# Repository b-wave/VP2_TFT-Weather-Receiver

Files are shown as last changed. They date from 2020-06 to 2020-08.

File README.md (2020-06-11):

# VP3-Weather-Receiver
*Davis Vantage Pro Weather Station Reciever using a Moteieino board with RFM69 and Color TFT Display.(1)*

This project is mainly a demo of the dekay/DavisRFM69 library (et.al.) @dekay using a TFT LCD screen 
it was intended to be a low-cost replacement for a broken Davis Vu Weather station that the ISS still works (with a few issues) 
*...but that is another story.* Hopefully *someone* will find this useful. I had a fun time developing it and
you can still see the saga of revisions in the source code listing as it evolved over several months. 

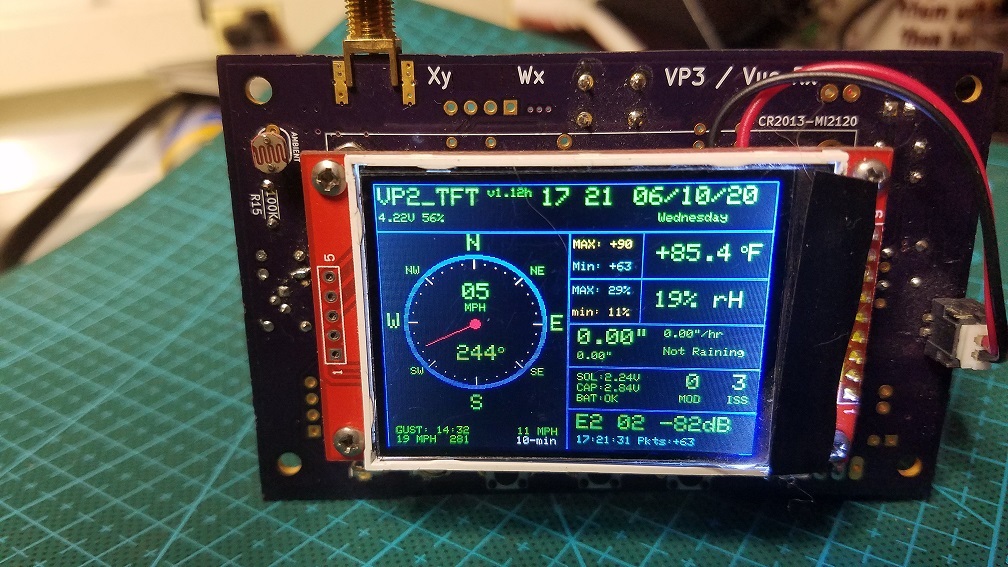
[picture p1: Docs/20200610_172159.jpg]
VP2_TFT-Weather-Receiver

Display in action - Front view

Because i used a low cost Motieno, https://lowpowerlab.com/ it ran out of memory so this version
can display mainly only the data received from the Davis Vantage Vu ISS.
With some derived info like,  max and mins, rain, and cool TFT wind compass displays. 

Curently, this project version does not  add the internal data to make a complete 
TFT console replacement for display of all weather parameters. I had to remove
indoor temp, humidity and barometric pressure to make a usable replacement. 

I designed a circuit board and added some usefull features such as push button setting
a LiPo battery backup and charger, and a real time clock.  Some features will need to move to
the: *next version that uses a Teensey 3.2 board will do all this and more!*

## CREDITS:
This is a derivitive work from several authors i give credit
to the original works in line as i use them, without their work
this would not be possible.  The original work here includes the
additions for using TFT LCD displays. But I credit to getting the 
TFT to work with the RFM69 was because of this excellent article:
 https://www.pjrc.com/better-spi-bus-design-in-3-steps/  
 Thanks Paul! @PaulStoffregen

https://github.com/kobuki/VPTools
VPTools is a Davis(TM) weather station compatible transceiver library. 
It is a work in progress. It can receive from multiple RF transmitters (ISS, ATK, etc.) 
It tries to serve as a basis for similar hobby projects. 
Example sketches provide simple, parseable and RAW packet output among others.

https://github.com/dekay/DavisRFM69  By DeKay
Licence: Creative Commons Attribribution Share-Alike License http://creativecommons.org/licenses/by-sa/3.0/
This library is a modified version of the LowPowerLab's RFM69 library that enables reception of weather data 
from a Davis Instruments Integrated Sensor Suite (ISS) weather station.

https://github.com/LowPowerLab/RFM69  By Felix Rusu, LowPowerLab.com 
RFM69 library for RFM69W, RFM69HW, RFM69CW, RFM69HCW (semtech SX1231, SX1231H) 
Licence:GPL 3.0, please see the License.txt file for details. 
Be sure to include the same license with any fork or redistribution of this library.

ADAFRUIT Libraries and awesome info:
Written by Limor Fried/Ladyada for Adafruit Industries. MIT license, 
Licence : MIT https://github.com/adafruit/RTClib/blob/master/LICENSE
https://github.com/adafruit

https://github.com/adafruit/RTClib
This is a fork of JeeLab's fantastic real time clock library for Arduino.

These libraries are for the Adafruit ILI9341 display products:  
https://github.com/adafruit/Adafruit_ILI9341
https://github.com/adafruit/Adafruit-GFX-Library

## Notes:
1. The VP3 refernce to the never produced color LCD console from Davis Instrumnents https://www.davisinstruments.com/weather-monitoring/
that all of us fans of thier products wish for.

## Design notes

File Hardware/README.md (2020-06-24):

*Davis Vantage Vu Weather Station Reciever using a Moteieino board with RFM69 and Color TFT Display*

This folder provides the hardware info for this project. The circuit board in the main page picture is an early version.  The current board will be available on OSH Park so you can just order boards if you want them as-is.  The main differences are some minor circuit fixes, a slight size adjustment (to fit in a case I have in mind for the station) and embedding the RTC and battery on the board.  The original PCB was ony intended to use plug in modules and make it a little more robust than protoboards.  From the software, which is pretty ugly, you can probabily tell I am not a software expert, but this board has a strange combo of thru-hole and SMT technologies that reflect mostly what was on hand or could get easily for this proto. is not making the hardware hall of fame either, but it works.   

# Schematic

The schematic is in KiCAD format, here it is as a .JPEG if you don't have that software. You will notice a lot of hardware features on the board are not in use in the VP3 console receiver project due to program storage space *(1)*.  If you order the boards from [OSH Park](https://oshpark.com/)  you get 3 boards so one can programmed to be a console, one can be a logger, and the third can be an APRS packet generator/controller.  ISS does not care how many receivers are listening! 

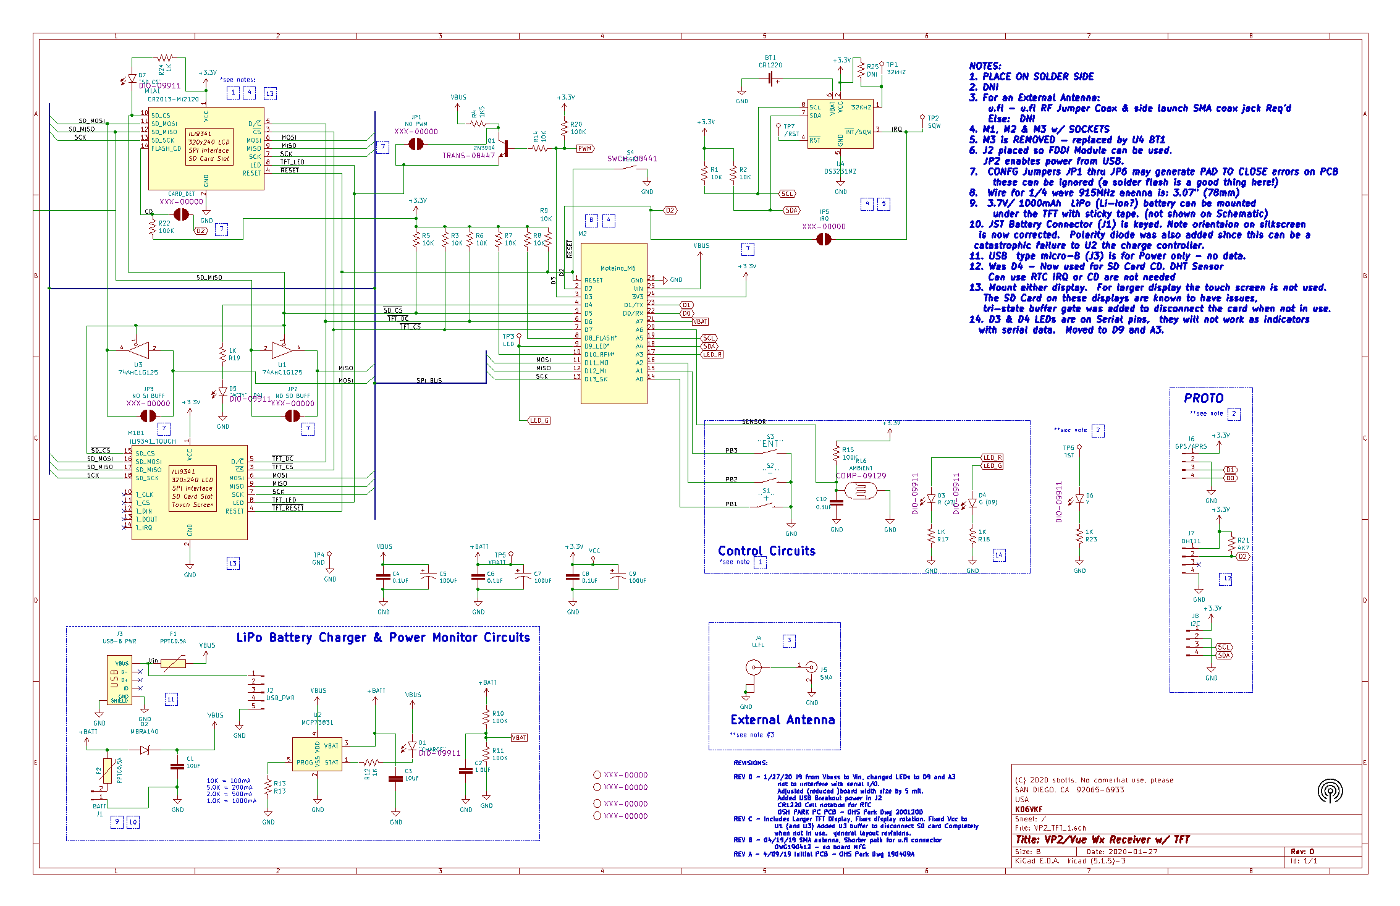
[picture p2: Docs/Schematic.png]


The circuit board is shown assembled in these 3D renderings.  The circuit board will accomodate 2 sizes of 320x240 displays. The 3D renderings also show the assembly with the smaller 2.2" display.  You can see the outline of the optional 2.8" display and that i Put the LED indicators outside its outline. The LiPo battery connector is on this side as well as it is sandwiched in between the display and main PCB.  There are 3 tactile switches:
**"+"  "-"  "GO!"**
Used to set the clock and other parameters. You may want to use the long plunger types (13mm - 15mm)  should reach thru a front or rear panel in this configuration especially if you are putting it in some sort of case. They can be mounted on either side of the board as well.  With the 2.8" display the swithes will need to be relocated as they are blocked from the front by that display. *(2)*

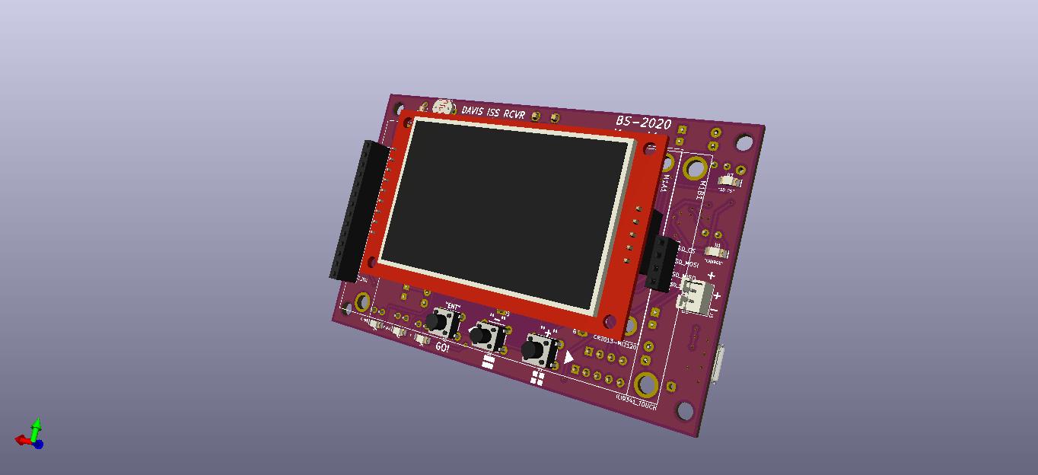
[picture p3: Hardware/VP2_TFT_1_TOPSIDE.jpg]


The back side is where the Moteino and other modules plug in. The power connectors are on the left side.  I used a mini-USB connector for just power.  The Pin out for the USB_Power_Only is setup to match the SPARKFUN Breakout board 
[BOB-09966](https://www.sparkfun.com/products/9966) enables a power plug to be moved depending on the case requirements. 

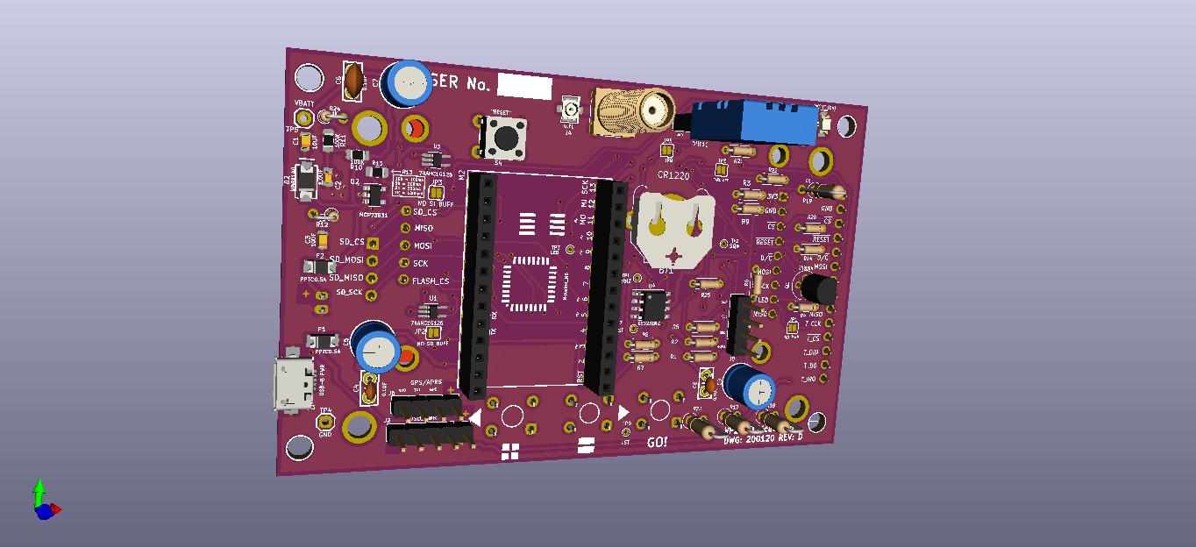
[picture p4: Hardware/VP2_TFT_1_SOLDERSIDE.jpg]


# Circuit Description

The  [Parts List](https://github.com/b-wave/VP2_TFT-Weather-Receiver/blob/master/Hardware/VP2_TFT_1.xlsx) is generated from the schematics, the format is wierd.  Not all parts are installed depending of software support and features. You may want to read through these circuit descriptions before getting parts. I also did not provide much specific supplier information yet, except for the few noted, the others are fairly common parts you can order from [Digikey](https://digikey.com) or [Mouser](https://mouser.com) or other simular suppliers. I may supply a complete parts list with suppliers used on OSH Park that are compatible with the version of board. 

* **Arduino.** The brains of this project is the **Low Power Lab** [Moteino](https://lowpowerlab.com/shop/product/99)  Remember when ordering that you must add the RFM69CW 868/916MHz RF Module option or you won't be receiving any data!  You can also get the RFM69HCW but that version has more transmit power that you really don't need for this project since we never transmit anything. Also, you can add the headers and possibly the memory chip but can use the on-chip non-volitile memory in the software. It come with a simple wire antenna that actully works OK. There is also a small $2.00 [915 MHz Helical Antenna](https://lowpowerlab.com/shop/product/160?search=antenna) you may consider ordering as well. Speaking of antennas, I went full up with a real ISM band rubber ducky antenna, that works fantasctic! But when is a good thing *too good?*  When you receive a neighbor's ISS, *from blocks away,* which seems not a big issue until you recive a rain count from it...it causes an erronious rain indication. For signal, the Motieno receiver decodes comfortably down to about -90dBm by my observations. If all else fails...there is a reset button (S4) that will restart the software.  This actully comes in more handy as the battery is always connected and you can't easily power cycle the unit. 

* **TFT Display.** The part that makes this a [Davis Vantage Vu](https://www.davisinstruments.com/solution/vantage-vue/) console is the TFT color LCD display. I used the ones that feature the ILI9341 chip in 240x320 QVGA resolution.  It turns out they that come in two sizes that work on the same software (see image below).  These are very common on e-bay and Amazon if you match the pinouts it should plug into the board just fine.  In the final version I intend to use the **Adafruit** versions for supply chain longevity i don't think the China clones will have. If you use the ones I found then thes will plug into the PCB directly.  You can jumper in others but if you want to use my software without modificaiton you need ILI9341 and 240x320 to be compatible. The two boards  used are 2.8" TFT SPI 240x320 v1.1 TJCTM24028-SPI and the smaller 2.2" CR2013-M12420 (the 2.2" version is shown in the pics).  Backlight is provided by white LEDs in the display. Reistor R4 sets the current to control the max brightness.  A PWM dimmer comprised of Q1 (NPN Transistor) R14 base resistor (10K) controled by one of he PWM pins (D3).  Note: R20 (100k) provides a pull up to keep the transistor turned on, even if D3 is not active in hi Z (input) state. The value from the AMBIENT Sensor can be used to dim the backlight. This sensor is described in the SENSORS section.  In a dark room, at full brightness, the LED puts out a lot of light!  The other reason we need to be able to dim it is for power savings on battery power, LEDs take a lot of current. If you want the display backlight on, set the brightness with R4, solder short the jumper J1, (see: JUMPERS) and DNI Q1, R14, and R20. Note: I did not see any noticable degredation in the RF perfomace while the PWM was running.  

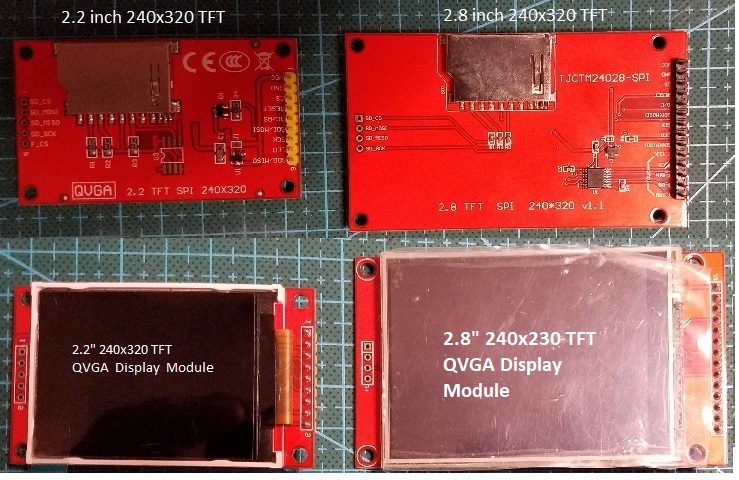
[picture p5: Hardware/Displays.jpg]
VP2_TFT Displays


[Two compatible TFT display boards]

* **SD Card.** The other feature of these TFT Displays is both have SPI controlled SD card sockets. I intended to use these as a data logging feature, but the current software does not support it. Also, in reading complaints and warnings about using these display SD cards I suspect there are SPI circuit issues so I added two buffer chips to try to eliminate these issues. The two 74AHC1G125 single-package gates U1 and U3 to only allow SPI traffic when the cards are specifically selected via the chip selet pin. This hardware will hopefully keep the SD cards from getting corrupted. To bypass these chips if it turns out we don't need to install the buffer(s), JP1 and JP2 will povide a non-switched path by soldering them closed with a blob of solder. LED D5 "ACTY" and R19 can be added to monitor the SD card activity. At this time the hardware and the logging feature have not been tested.

* **RTC.** The original prototype used a RTC on a board. This is easy to breadboard with but takes a lot of board space and height. I thought it would be OK, considering the Motieno is on a socket too, but decided to try an embedded approach in this version using a compact **SO-8**  *-z*  version of the **DS3231Z chip**.  Time is backed up by a coin cell (BT1).  See Batteries section.
* **Sensors.**  Several on board sensors and conectors for sensors are provided.  
  * **Voltage sensor.** Consists of two high-value resistors (100k) R10 and R11 Take the input voltage of the battery and divide it in half. Capacitor C2 can be used for smoothing or noise reduction if needed, this signal is fed into VBATT (Analog Pin A7).  The voltage is scaled and is currently only used as a display of the battery voltage as a charge indication. 
  * **Ambient Sensor.**  An analog voltage proportional to the ambient light is provide by a voltage divider formed by R16 a **LDR** and scaled by R16 (100k). A capacitor (C10) is provided to smooth the voltage input. The sensor used was harvested from a broken lawn solar light. 
  * **Indoor Humidity and Tempature Sensor.**  J7 provides a pin compatible connector for this sensor. It has a unique interface provided into pin D2 with a 4.7K pull up (R21)  These integrated temp/humidity sensors are pretty common on Amazon and other suppliers.  This was only used in early code versions before i relized there would not be enough code storage space on the Moteuino board. 
  * **Barometric Sensor.** J8 is an i2C connector arranged with voltage and ground pins to match an  I2C mems barometer breakout board, alas, i did not have code space to keep it.  Pins A5 and A4 provide the i2C SCL and SDA signals. Any other I2C board can work with these pins as well. 
* **LEDs.** Several LEDs indicators are also sprinkled around the board, mostly for debugging, and what fun is having no blinking lights?

LED| Label | Function
------------ | ------------ | -------------
D1| CHARGE | MCP73831 STAT Pin "Charging"
D3| Red |  Controlled by Pin A3, flashes for bad stuff
D4| Green |Controlled by Pin D9 (same as Motieno LED) good stuff
D5| ACTY | Controlled by Pin D4 to show some status? Maybe as SD card issues?
D6| Yellow | (DNI) TP6 connect if needed for debug, visible from front panel 
D7| SD_CS | on if SD Card chip is selected (SPI activity)

* **Back up Batteries.**  
Two battery circuits are provided for back up purposes. 

  * **Main Power** The provided battery charger circuit is intended to keep the main battery charged and take over in the event of a power failure or if you just want to move the receiver around.  It keeps the Max/Mins and rain totals in memory as well. The charge controller is a (U2) MCP73831.   An and old cell phone battery was used with a soldered JST type battery pigtail from [Adafruit](https://www.digikey.com/product-detail/en/adafruit-industries-llc/1131/1528-1494-ND/5761282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). It  but it fit nicely between the board and display and holds a charge long enough. I did not connect the other pad(s)on the battery, which is probabily a thermistor or battery ID pin, which is not needed in this circuit only "+" and "-". The battery connector BATT (J1) is a standard JST_PH_B2B-PH-K_1x02_P2.00mm_Vertical common for batteries and is polarized. 
  
[Battery figure here?]

The charging current is set by R13.  For this application, a large (10K or larger) resistor should be used to just maintain the battery charge at 100mA or even less, I used an old battery, that may now suck as a cell phone battery, but it is only intended to run for *a few hours at most* and is not intended to be a portable device *per se*, so a slow charge is fine. When the battery is charging LED (D1) is on and turns off when a full charge is reached. Input power (5V) comes from J2 or J3 and the battery takes over when the supply is unplugged or interrupted. An MBRA140 SHOTTKY Diode (D2) diode switches depending on the voltage difference of Vin and Vbatt. The voltage sensor (described in the Sensors Section) circuit can be used to monitor the voltage on the batery to let you know when it it time to plug in, but we only use that for display.  

Also, two PTC fuses are provided (F1, F2) to protect the circuits. F1 is a .5A PTC resettable fuse that protects the circuitry when powered by an external power supply from (J2 or J3). F2 is in-line with the battery from  (J1)  in case there is too much current from the battery. F1 is the most importaint as the console is intended to be plugged in most of the time.  F2 is only if there is a battery issue, which is an unlikely possibility, but if the device is dropped or worse yet stepped on which can cause a short and these little batteries contain a lot of energy. If you do accidentally trip one of these they heat up and essentally open then reset themselves when they cool down. 
  * **RTC Backup**  BT1 is the RTC back up. I  reduced the battery from the standard **CR2023** 3V Li Coin cell to a smaller **CR1220**.  I am not sure how long this cell will last, but that is only really needed if the main power *and* the battery back up fails as well.  The holder is soldered to the circuit board.
  
* **Connectors and Misc.**  Here are descriptions of the various connectors, jumpers, and test points on the board. Various *"solder blob"* configuraton jumpers (JP) are on the board to bypass or enable some features.  Pin D2 is selectabe between one of two features, shown below I don't think both will be usable at the same time so it is an either/or selecton for it

ITEM | Label | Type |Function
----- | -------- | ------------ | -------------
J1| BATT | 2-pin JST | LiPo Battery 
J2 | USB_POWER_ONLY  | Header, 5-Pin, 0.1"  | SparkFun USB Breakout board (+5V, GND No data pins)
J3 | USB-B POWER  | USB Mini-B, SMT | USB VBUS Power Only (+5V,  GND  No Data pins) 
J4 | EXTERNAL ANTENNA  | U.FL RF COAX  | Connects Board to Moteino Antenna 
J5 | EXTERNAL ANTENNA   | SMA (R-P or NORM)   | Antenna Connector
J6 | GPS/APRS  | Header, 4-Pin, 0.1"  | Serial data (D0, D1 ) + 3.3V Power + GND
J7 | DHT-11   | Header, 4 Pin 0.1"  | Humidity and Temp Sensor 
J8 | I2C  | Header, 4-pin 0.1"   | Baro Sensor or other I2C, SCL SDA 3.3V POWER GND
JP1 | NO PWM  |  SMT Jumper | To Bypass Backlight PWM Transistor Q1
JP2 | NO SI BUFF   | SMT Jumper  | Bypass MOSI Switch  U3 to SD Card
JP3 | NO SO BUFF   | SMT Jumper |  Bypass MISO Switch U1 from SD Card
JP4 | N/A   | N/A   | Not used - removed from board version
JP5 | IRQ   | SMT Jumper   | Connects RTC IRQ to pin D2
JP6 | CARD DET  | SD card inserted  | No card = low Connects to pin D2
TP1 | 32KHZ  | Test Point  | RTC 32KHz Output
TP2 | SQW  | Test Point  | RTC Square Wave Output (for interrupt)
TP3 | LED  | Test Point  | Moteino LED Signal (D9)
TP4 | GND  | Test Point  | Power / Test Ground
TP5 | VBATT | Test Point  | Battery Voltage
TP6 | TST  | Test Point  | Connetct a digital signal to LED6 ( or Peizo Speaker!) 
TP7 | /RST   | Test Point  | RTC Reset, GND = Resets RTC clock

 * **NOTES** 
   * *1.  I have started a version that uses a Teensey 3.2 for more software space.  Early versions show promise as it now sucessfully communicates to the RF-69 radio and TFT.*
   * *2. The 2.8" display has a touch screen but the pins are not connected in in this version.*

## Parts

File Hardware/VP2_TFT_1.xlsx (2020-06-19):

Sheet: VP2_TFT_1_BOM
Ref | Qnty | Value | Part | Description | Vendor
BT1 | 1 | CR1220 | TH COIN CELL BATTERY HOLDER 12mm, KEYSTONE Part # 3001 or equiv. | https://www.mouser.com/datasheet/2/215/001-743291.pdf https://www.mouser.com/ProductDetail/12BH062-GR | MOUSER
C1, C3 | 2 | 10UF | CAPACITOR:10UF-0805-10V-10%
C2 | 1 | 1.0UF | CAPACITOR:1.0UF-0805-25V-10%
C4, C6, C8 | 3 | 0.1UF | CAPACITOR:0.1UF-KIT-EZ-50V-20% | Some Thru hole Bypass caps
C5, C7, C9 | 3 | 100UF | CAPACITOR100UF-POLAR-RADIAL-2.5MM-25V-20% | Some Thru hole Bypass caps
C10 | 1 | 0.1UF | CAPACITOR:1.0UF-0805-25V-10%
D1 | 1 | "CHARGE" | DIODE:LED-BLUE1206
D2 | 1 | MBRA140 | DIODE: SHOTTKY, MBRA140 | 863-MBRA140T3G (https://www.mouser.com/ProductDetail/863-MBRA140T3G) | MOUSER
D3 | 1 | R (A3) | DIODE:LED-RED 1206
D4 | 1 | G (D9) | DIODE:LED-GREEN 1206
D5 | 1 | "ACTY" (D4) | DIODE:LED-BLUE 1206
D6 | 1 | Y | DIODE:LED,YELLOW 1206
D7 | 1 | "SD CS" | DIODE:LED,BLUE1206
F1, F2 | 2 | PPTC0.5A | FUSE, PPTC_HALF,AMP, 1206 | https://www.mouser.com/ProductDetail/576-1206L050YR | MOUSER
H1, H2, H3, H4 | 4 | STAND,OFF | 1/8" plated HOLE, #4 Hardware | Hole Pads on PCB – No Part needed
J1 | 1 | BATT | Connector, JST-PH, 01x02_Male | Plug: https://www.adafruit.com/product/1131?gclid=EAIaIQobChMI5fn-n8OJ6gIVID6tBh2I5wpgEAQYBiABEgLWS_D_BwE
J2 | 1 | USB_PWR | Connector, Header, 01x05_Male
J3 | 1 | USB-B PWR | CONNECTOR, USB_MICRO-B_SMT | 656-DX4R005HJ5R2000 (https://www.mouser.com/ProductDetail/656-DX4R005HJ5R2000) | MOUSER
J4 | 1 | U.FL | CONNECTOR, RF, U.FL
J5 | 1 | SMA | Connector, RF, Coaxial, Thru-Hole | RF Connectors / Coaxial Connectors RP-SMA Female PCB Mnt, Extended, Gold MOUSER PN 712-CONREVSMA008-G | LINX TECHNOLOGIES
J6 | 1 | GPS/APRS | GPS Module, Serial, GPS NEO-6M GPS, Connector: Header, 01x04_Male | https://www.google.com/url?rct=j&q=&esrc=s&cd=&cad=rja&uact=8
J7 | 1 | DHT11 | Connector: Header, 01x04_Male | https://www.mouser.com/datasheet/2/758/DHT11-Technical-Data-Sheet-Translated-Version-1143054.pdf
J8 | 1 | I2C | Sensor, BMP280, Connector: Header, 01x04_Male | I think it was this one: https://www.amazon.com/ACROBOTIC-Temperature-Barometric-Raspberry-Altimeter/dp/B07HVFB9M9
JP1 | 1 | NO PWM | JUMPER-SMT_2_NO-SparkFun-Jumpers | Solder Pads on PCB – No Part needed
JP2 | 1 | NO SO BUFF | :JUMPER-SMT_2_NO-SparkFun-Jumpers | Solder Pads on PCB – No Part needed
JP3 | 1 | NO SI BUFF | :JUMPER-SMT_2_NO-SparkFun-Jumpers | Solder Pads on PCB – No Part needed
JP5 | 1 | IRQ | :JUMPER-SMT_2_NO-SparkFun-Jumpers | Solder Pads on PCB – No Part needed
JP6 | 1 | CARD_DET | :JUMPER-SMT_2_NO-SparkFun-Jumpers | Solder Pads on PCB – No Part needed
M1A1 | 1 | CR2013-MI2120 | DISPLAY, TFT, QVGA, 2.2 INCH, CR2013-MI2120 | ILI9341 controller, SPI TFT LCD Display, 9-pin breakout PCB, 4-pin SD card interface, 5V/3.3V
M1B1 | 1 | ILI9341_TOUCH | DISPLAY, TFT, QVGA, 2.8 INCH, ILI9341_TOUCH-TFT | ILI9341 controller, SPI TFT LCD Display w/Touch Screen, 13-pin breakout PCB, 4-pin SD card interface, 5V/3.3V
M2 | 1 | Moteino_M6 | ARDUINO , Moteino_M6-MCU, Module | https://lowpowerlabs.com
Q1 | 1 | 2N3904 | TRANSISTOR, NPN-2N3904, TO92
R1, R2, R5, R6, R7, R8, R14 | 7 | 10K | RESISTOR, AXIAL, 1/8WATT | Resistor, US symbol
R3, R9 | 2 | 10K | RESISTOR, AXIAL, 1/8WATT | Resistor, US symbol
R4 | 1 | 1K5 | RESISTOR, AXIAL, 1/8WATT | Resistor, US symbol
R10, R11 | 2 | 100K | RESISTOR, 0805, 1/16W, 1% | Resistor, US symbol
R12, R24 | 2 | 1K | RESISTOR, AXIAL, 1/8WATT | Resistor, US symbol
R13 | 1 | 4k7 | RESISTOR, 0805, 1/16W, 1% | Resistor, US symbol
R15, R20, R22 | 3 | 100K | RESISTOR, AXIAL, 1/8WATT | Resistor, US symbol
R16 | 1 | AMBIENT | RESISTOR, Photo Cel,l CdS Photoresistor | MOUSER PART # 485-161 | ADAFRUIT
R17, R18, R23 | 3 | 1K | RESISTOR, AXIAL, 1/8WATT | Resistor, US symbol
R19 | 1 | 1K | RESISTOR, AXIAL, 1/8WATT | Resistor, US symbol
R21 | 1 | 4K7 | RESISTOR, AXIAL, 1/8WATT | Resistor, US symbol
S1 | 1 | GO! | SWITCH, MOMENTARY, SPST-PTH-6.0MM
S2 | 1 | "-" | SWITCH, MOMENTARY, SPST-PTH-6.0MM
S3 | 1 | "+" | SWITCH, MOMENTARY, SPST-PTH-6.0MM
S4 | 1 | "RESET" | SWITCH, MOMENTARY, SPST-PTH-6.0MM
U1, U3 | 2 | 74AHC1G125 | IC, Single Gate 74xGxx, 74AHC1G125 | SINGLE NON INVERTING DRIVER 3-STATE Low-Voltage CMOS, 621-74AHC1G125SE-7 | MOUSER
U2 | 1 | MCP73831 | IC, Battery Management, Li-Ion/Li-Po charge controller, 4.20V, MCP73831-2-OT, SOT23-5 | 700-DS3231MZ+ https://www.mouser.com/ProductDetail/700-DS3231MZ%2b 579-MCP73831T-2ACIOT | MOUSER
U4 | 1 | DS3231MZ | IC, Timer RTC, DS3231MZ, ±5ppm, I2C Real-Time Clock SOIC-8, | https://www.mouser.com/QuickViewProdDetail.aspx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 | MOUSER

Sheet: VP2_TFT_1
Id;"Designator";"Package";"Quantity";"Designation";"Supplier and ref";
1;"M2";"MoteinoM6";1;"Moteino_M6";;;
2;"BT1";"BatteryHolder_Keystone_3001_1x12mm";1;"BATTERY-20MM_PTH";;;
3;"U4";"SOIC-8_3.9x4.9mm_P1.27mm";1;"DS3231MZ";;;
4;"J5";"SMA_Amphenol_132291-12_Vertical";1;"SMA";;;
5;"F2 | F1";"1206";2;"PPTC0.5A";;;
6;"JP6";"SMT-JUMPER_2_NO_SILK";1;"CARD_DET";;;
7;"R22 | R10 | R11 | R15 | R20";"R_Axial_DIN0204_L3.6mm_D1.6mm_P5.08mm_Horizontal";5;"100K";;;
8;"JP5";"SMT-JUMPER_2_NO_SILK";1;"IRQ";;;
9;"C8 | C6 | C4";"CAP-PTH-SMALL-KIT";3;"0.1UF";;;
10;"C9 | C7 | C5";"CPOL-RADIAL-2.5MM-6.5MM";3;"100UF";;;
11;"J4";"U.FL";1;"U.FL";;;
12;"S3";"TACTILE_SWITCH_PTH_6.0MM";1;""+"";;;
13;"H1 | H2 | H3 | H4";"STAND-OFF";4;"STAND-OFF";;;
14;"S4";"TACTILE_SWITCH_PTH_6.0MM";1;""RESET"";;;
15;"TP1";"1X01";1;"32kHZ";;;
16;"R1 | R2 | R3 | R5 | R6 | R7 | R8 | R9 | R14";"R_Axial_DIN0204_L3.6mm_D1.6mm_P5.08mm_Horizontal";9;"10K";;;
17;"R4";"R_Axial_DIN0204_L3.6mm_D1.6mm_P5.08mm_Horizontal";1;"1K5";;;
18;"U1";"SOT-353_SC-70-5_Handsoldering";1;"74AHC1G125";;;
19;"C1 | C3";"0805";2;"10UF";;;
20;"D1";"LED-1206";1;""CHARGE"";;;
21;"D2";"SMA-DIODE";1;"MBRA140";;;
22;"R12 | R17 | R18 | R19";"R_Axial_DIN0204_L3.6mm_D1.6mm_P5.08mm_Horizontal";4;"1K";;;
23;"R13";"R_Axial_DIN0204_L3.6mm_D1.6mm_P5.08mm_Horizontal";1;"4k7";;;
24;"U2";"SOT-23-5";1;"MCP73831";;;
25;"S1";"TACTILE_SWITCH_PTH_6.0MM";1;"GO!";;;
26;"J1";"JST_PH_B2B-PH-K_1x02_P2.00mm_Vertical";1;"BATT";;;
27;"J3";"USB-MICROB";1;"USB-B PWR";;;
28;"Q1";"TO-92";1;"2N3904";;;
29;"R16";"PHOTOCELL";1;"AMBIENT";;;
30;"S2";"TACTILE_SWITCH_PTH_6.0MM";1;""-"";;;
31;"C2";"0805";1;"1.0UF";;;
32;"D3";"LED-1206";1;""OK"";;;
33;"D4";"LED-1206";1;""ERR"";;;
34;"D5";"LED-1206";1;""ACTY"";;;
35;"JP4";"SMT-JUMPER_3_1-NC_TRACE_SILK";1;"TFT RES";;;
36;"J6";"PinHeader_1x04_P2.54mm_Vertical";1;"GPS/APRS";;;
37;"J7";"PinHeader_1x04_P2.54mm_Vertical";1;"DHT11";;;
38;"J8";"PinHeader_1x04_P2.54mm_Vertical";1;"I2C";;;
39;"J9";"1X02";1;"VBUS";;;
40;"R21";"R_Axial_DIN0204_L3.6mm_D1.6mm_P5.08mm_Horizontal";1;"4K7";;;
41;"JP2";"SMT-JUMPER_2_NO_SILK";1;"NO SO BUFF";;;
42;"JP1";"SMT-JUMPER_2_NO_SILK";1;"NO PWM";;;
43;"M1A1";"CR2013-MI2120";1;"CR2013-MI2120";;;
44;"M1B1";"ILI9341_TFT_TOUCH";1;"ILI9341_TOUCH";;;

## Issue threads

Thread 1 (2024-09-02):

Sketch Fails to Compile after Upgrade to Arduino IDE 3.2.3

b-wave, 2024-09-02:
After upgrading to IDE 3.2.3 from 1.8.19 the sketch will no longer compile.  I tried rolling back to 1.8.19 but gives the same error.  The last good compile on 07/26/2020 V1.13D was on the edge of memory limits but compiled just fine.  The last time i recorder memory usage it was using approximately:

 31220 bytes (98%) of program storage space. Maximum is 31744 bytes.
 Global variables use 931 bytes of dynamic memory. W/O DEBUG ENABLED

I don't see any DEBUG enabled.  I suspect since there are some multiple libraries found during the compile, there may be smaller versions not used.  If i find which ones work i will add the working libs to this repository.

Multiple libraries were found for "EEPROM.h"
Multiple libraries were found for "DavisRFM69.h"

maybe there are some compiler options that got changed during the upgrade that affect both versions.

ERROR MESSAGE:
Sketch uses 33672 bytes (106%) of program storage space. Maximum is 31744 bytes.

Global variables use 941 bytes (45%) of dynamic memory, leaving 1107 bytes for local variables. Maximum is 2048 bytes.
Sketch too big; see https://support.arduino.cc/hc/en-us/articles/360013825179 for tips on reducing it.
text section exceeds available space in board

Compilation error: text section exceeds available space in board

b-wave, 2024-09-03:
Compiles fine with Arduino Mega or Mega2:

Sketch uses 35584 bytes (14%) of program storage space. Maximum is 253952 bytes.

Global variables use 955 bytes (11%) of dynamic memory, leaving 7237 bytes for local variables. Maximum is 8192 bytes.

Closed 2024-09-03.

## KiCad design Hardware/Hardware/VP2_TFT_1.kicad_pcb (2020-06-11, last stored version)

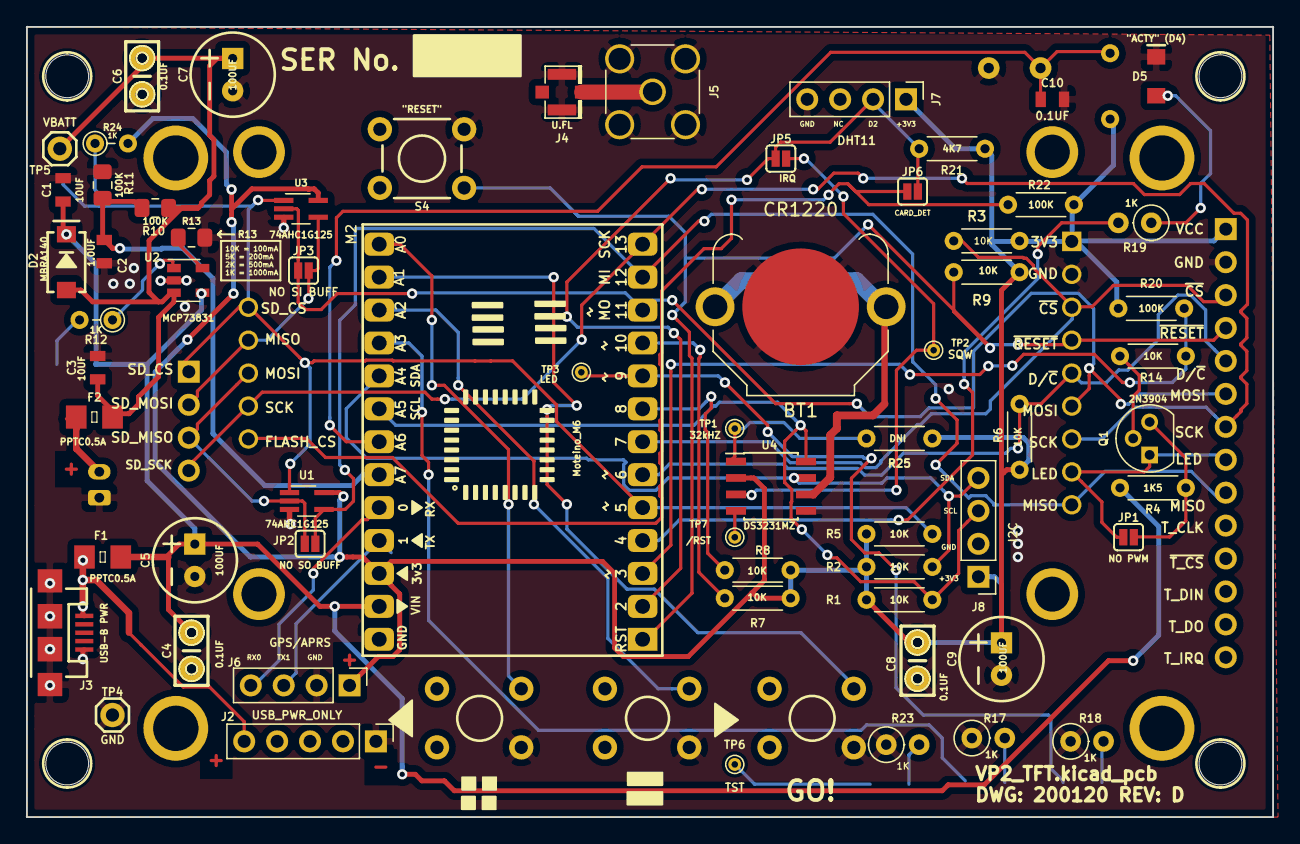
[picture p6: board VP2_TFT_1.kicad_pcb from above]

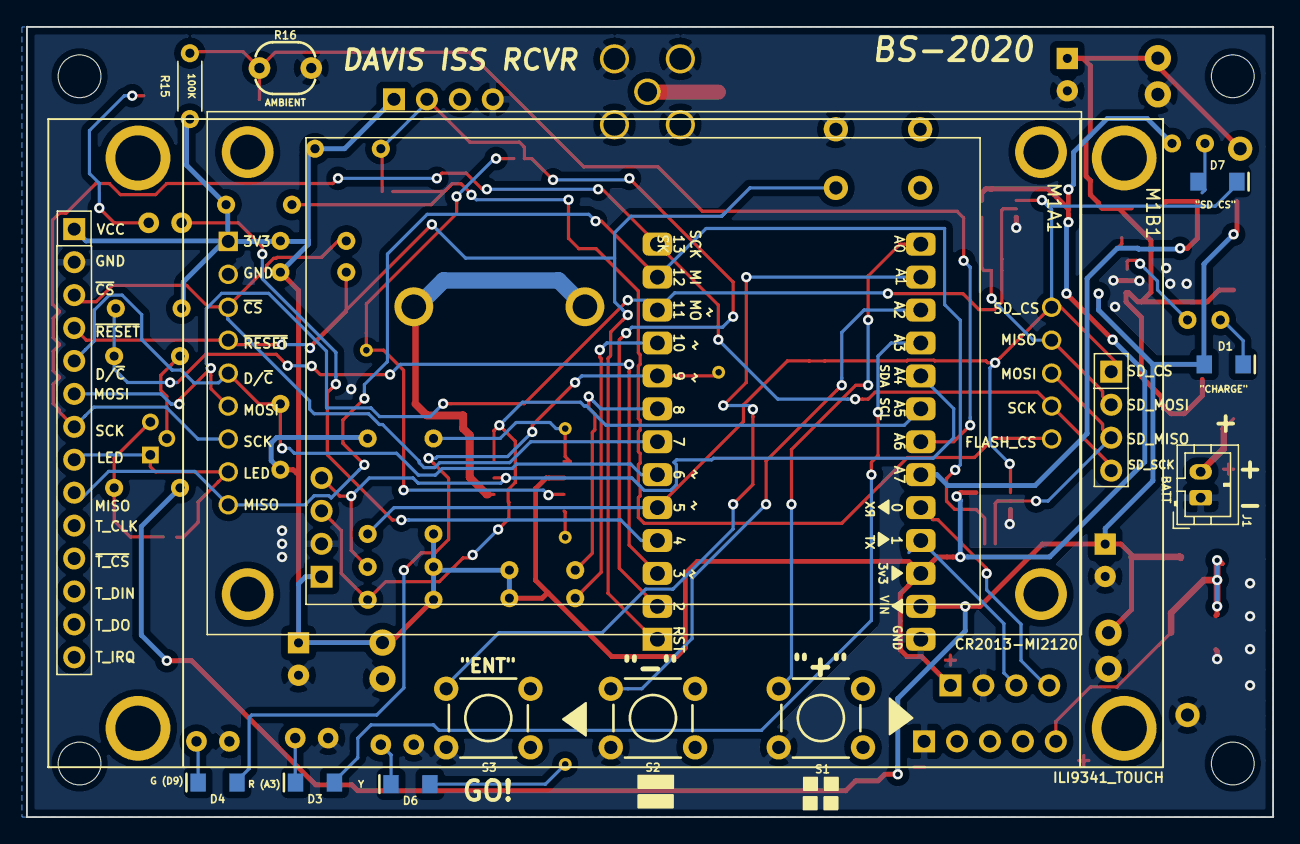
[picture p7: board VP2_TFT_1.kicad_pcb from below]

Board: 2 copper layers, 96.1 x 61.0 mm, 81 parts (13 on the bottom side), 49 nets.

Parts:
BT1: CR1220; BatteryHolder_Keystone_3001_1x12mm
C1, C3: 10UF; 0805
C2: 1.0UF; 0805
C4, C6, C8: 0.1UF; CAP-PTH-SMALL-KIT
C5, C7, C9: 100UF; CPOL-RADIAL-2.5MM-6.5MM
C10: 0.1UF; 0805
D1: "CHARGE"; LED-1206
D2: MBRA140; SMA-DIODE
D3: R (A3); LED-1206
D4: G (D9); LED-1206
D5: "ACTY" (D4); LED-1206
D6: Y; LED-1206
D7: "SD CS"; LED-1206
F1, F2: PPTC0.5A; 1206
H1, H2, H3, H4: STAND-OFF
J1: BATT; JST_PH_B2B-PH-K_1x02_P2.00mm_Vertical
J2: USB_PWR_ONLY; PinHeader_1x05_P2.54mm_Vertical
J3: USB-B PWR; USB-MICROB
J4: U.FL
J5: SMA; SMA_Amphenol_132291-12_Vertical
J6: GPS/APRS; PinHeader_1x04_P2.54mm_Vertical
J7: DHT11; PinHeader_1x04_P2.54mm_Vertical
J8: I2C; PinHeader_1x04_P2.54mm_Vertical
JP1: NO PWM; SMT-JUMPER_2_NO_SILK
JP2: NO SO BUFF; SMT-JUMPER_2_NO_SILK
JP3: NO SI BUFF; SMT-JUMPER_2_NO_SILK
JP5: IRQ; SMT-JUMPER_2_NO_SILK
JP6: CARD_DET; SMT-JUMPER_2_NO_SILK
M1A1: CR2013-MI2120
M1B1: ILI9341_TOUCH; ILI9341_TFT_TOUCH
M2: Moteino_M6; MoteinoM6
Q1: 2N3904; TO-92
R1, R2, R3, R5, R6, R7, R8, R9, R14: 10K; R_Axial_DIN0204_L3.6mm_D1.6mm_P5.08mm_Horizontal
R4: 1K5; R_Axial_DIN0204_L3.6mm_D1.6mm_P5.08mm_Horizontal
R10, R11: 100K; R_0805_2012Metric_Pad1.15x1.40mm_HandSolder
R12, R24: 1K; R_Axial_DIN0204_L3.6mm_D1.6mm_P2.54mm_Vertical
R13: R13; R_0805_2012Metric_Pad1.15x1.40mm_HandSolder
R15, R20, R22: 100K; R_Axial_DIN0204_L3.6mm_D1.6mm_P5.08mm_Horizontal
R16: AMBIENT; PHOTOCELL
R17, R18, R19, R23: 1K; R_Axial_DIN0207_L6.3mm_D2.5mm_P2.54mm_Vertical
R21: 4K7; R_Axial_DIN0204_L3.6mm_D1.6mm_P5.08mm_Horizontal
R25: DNI; R_Axial_DIN0204_L3.6mm_D1.6mm_P5.08mm_Horizontal
S1: "+"; TACTILE_SWITCH_PTH_6.0MM
S2: "-"; TACTILE_SWITCH_PTH_6.0MM
S3: "ENT"; TACTILE_SWITCH_PTH_6.0MM
S4: "RESET"; TACTILE_SWITCH_PTH_6.0MM
TP1: 32kHZ; TestPoint_THTPad_D1.0mm_Drill0.5mm
TP2: SQW; TestPoint_THTPad_D1.0mm_Drill0.5mm
TP3: LED; TestPoint_THTPad_D1.0mm_Drill0.5mm
TP4: GND; 1X01
TP5: VBATT; 1X01
TP6: TST; TestPoint_THTPad_D1.0mm_Drill0.5mm
TP7: /RST; TestPoint_THTPad_D1.0mm_Drill0.5mm
U1, U3: 74AHC1G125; SOT-353_SC-70-5_Handsoldering
U2: MCP73831; SOT-23-5
U4: DS3231MZ; SOIC-8_3.9x4.9mm_P1.27mm

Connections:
+3V3: C8.1, C9.1, J6.1, J7.1, J8.1, M1A1.1, M1B1.1, M2.24, R1.1, R2.1, R3.1, R5.1, R6.1, R7.1, R8.1, R9.1, R15.1, R20.1, R21.1, R22.2, R24.2, R25.1, U1.5, U3.5, U4.2
+BATT: C3.1, C6.1, C7.1, D2.A, F2.2, R10.1, TP5.1, U2.3
/CD: JP6.1, M1A1.14, R22.1
/IRQ: JP5.2, TP2.1, U4.3
/MISO: JP2.2, M1A1.9, M1B1.9, M2.12, U1.4
/MOSI: JP3.1, M1A1.6, M1B1.6, M2.11, U3.2
/PB1: M2.14, S1.1
/PB2: M2.16, S2.1
/PB3: M2.15, S3.1
/SCK: M1A1.7, M1A1.13, M1B1.7, M1B1.18, M2.13
/SD_MISO: JP2.1, M1A1.12, M1B1.17, U1.2
/SD_MOSI: JP3.2, M1A1.11, M1B1.16, U3.4
/SENSOR: C10.1, M2.20, R15.2, R16.1
/TFT_LED: JP1.1, M1A1.8, M1B1.8, Q1.1
/Vin: F1.1, J2.5, J3.VBUS
/~RESET: M1A1.4, M1B1.4, M2.1, R9.2, S4.1
/~SD_CS: D7.C, M1A1.10, M1B1.15, M2.5, R5.2, U1.1, U3.1
/~TFT_CS: M1A1.3, M1B1.3, M2.7, R3.2
/~TFT_DC: M1A1.5, M1B1.5, M2.6, R6.2
D0: J6.4, M2.22
D1: J6.3, M2.23
D2: J7.2, JP5.1, JP6.2, M2.2, R21.2
GND: BT1.2, C1.2, C2.2, C3.2, C4.2, C5.2, C6.2, C7.2, C8.2, C9.2, C10.2, D5.C, J1.1, J2.1, J3.GND, J3.MT1, J3.MT2, J3.P$1, J3.P$2, J4.1, J4.2, J5.2, J6.2, J7.4, J8.2, M1A1.2, M1B1.2, M2.26, R11.2, R13.2, R16.2, R17.1, R18.1, R23.1, S1.3, S2.3, S3.3, S4.3, TP4.1, U1.3, U2.2, U3.3, U4.5
LED_G: D4.A, M2.9, TP3.1
LED_R: D3.A, M2.17
unnamed: BT1.1, U4.6
unnamed: D1.C, R12.2
unnamed: D3.C, R17.2
unnamed: D4.C, R18.2
unnamed: D5.A, R19.1
unnamed: D6.A, TP6.1
unnamed: D6.C, R23.2
unnamed: D7.A, R24.1
unnamed: F2.1, J1.2
unnamed: J4.FEED, J5.1
unnamed: JP1.2, Q1.3, R4.2
unnamed: M2.4, R19.2
unnamed: M2.8, R8.2
unnamed: M2.10, R7.2
unnamed: Q1.2, R14.1
unnamed: R12.1, U2.1
unnamed: R13.1, U2.5
unnamed: R25.2, TP1.1, U4.1
unnamed: TP7.1, U4.4
PWM: M2.3, R14.2, R20.2
SCL: J8.3, M2.19, R1.2, U4.8
SDA: J8.4, M2.18, R2.2, U4.7
VBAT: C2.1, M2.21, R10.2, R11.1
VBUS: C1.1, C4.1, C5.1, D1.A, D2.C, F1.2, M2.25, R4.1, U2.4

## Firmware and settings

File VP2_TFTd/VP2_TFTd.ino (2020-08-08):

/*******************************************************************
This is a demo of the dekay/DavisRFM69 library using a TFT LCDscreen 
for a Weather Receiver console replacement. 

It displays only  the data received from the Davis Vantage Vu ISS.
Curently, this version does not  add the internal data to make a complete 
TFT console replacement for display of all weather parameters.

This is mostly a derivitive work from several authors i give credit
to the original works in line as i use them, without their work
this would not be possible.  The original work here includes the
additions for using TFT LCD displays. But I credit to getting the 
TFT to work with the RFM69 was because of this excellent article:
 https://www.pjrc.com/better-spi-bus-design-in-3-steps/  Thanks Paul! 

This project was intended to be a low cost replacement for a broken 
Davis Vu Weather staion that the ISS still works (with a few issues) 
but that is another story. Hopefully someone can find this useful.

https://github.com/kobuki/VPTools
VPTools is a Davis(TM) weather station compatible transceiver library. 
It is a work in progress. It can receive from multiple RF transmitters (ISS, ATK, etc.) 
It tries to serve as a basis for similar hobby projects. 
Example sketches provide simple, parseable and RAW packet output among others.


https://github.com/dekay/DavisRFM69  By DeKay
Licence: Creative Commons Attribribution Share-Alike License http://creativecommons.org/licenses/by-sa/3.0/
This library is a modified version of the LowPowerLab's RFM69 library that enables reception of weather data 
from a Davis Instruments Integrated Sensor Suite (ISS) weather station.

https://github.com/LowPowerLab/RFM69  By Felix Rusu, LowPowerLab.com 
RFM69 library for RFM69W, RFM69HW, RFM69CW, RFM69HCW (semtech SX1231, SX1231H) 
Licence:GPL 3.0, please see the License.txt file for details. 
Be sure to include the same license with any fork or redistribution of this library.

ADAFRUIT Libraries and awesome info:
Written by Limor Fried/Ladyada for Adafruit Industries. MIT license, 
Licence : MIT https://github.com/adafruit/RTClib/blob/master/LICENSE
https://github.com/adafruit

https://github.com/adafruit/RTClib
This is a fork of JeeLab's fantastic real time clock library for Arduino.

These libraries are for the Adafruit ILI9341 display products:  
https://github.com/adafruit/Adafruit_ILI9341
https://github.com/adafruit/Adafruit-GFX-Library


 
02/25/2019  V0.1 (c)SBOTTS Basic Layout of TFT
02/26/2019  V0.2 Test WIND Compass 
02/27/2019  V0.3 Clock and Flashing Seconds 
            V0.31 Test DHT sensor
03/02/2019  V0.41 Updates to Cells using internal Temp Humidity
            V0.42 Inverts cells to show selected. Fixed multiple updates DHT
03/04/2019  V1.00 Initial version with DavisRFM69  
            V1.01 Replace inside with outside data but no wx data to screen
                  does not seem to be decoding incoming data.
                  clock updating, Not bad progress! 
            V1.02 Changed OK_LED pin 3 was conflicting with RTC interrupt.   
                  Added some prints to see what was going on.
                  Receiving wx on channel 2
03/05/2019  V1.03 Added Packet and Radio status displays for TFT,
                  moved positions of cells to display only outside and
                  radio data. Changed ID to #3.  Works! Sort of...
                  Runs but locks up after about 5 min.  
                  Maybe too many nested calls and interrupt? 
                  5170 bytes (79%) of program storage space.
03/05/2019  V1.04 I think there is a SPI conflict! DavisRFM69 uses SPI in the interrupt.
                  See: https://www.pjrc.com/better-spi-bus-design-in-3-steps/
                  So need to add this for RFM69: SPI.usingInterrupt(RF69_IRQ_NUM); or RF69_IRQ_PIN
                  Also add pullups to the CS pins for better design.  
                  
                  Added some rain functions too...
                  28314 bytes (89%) of program storage space.<<may need to remove internal temp and baro 
03/05/2019  V1.05 Masive clean up.  Reset rain at midnight removing debug code.                    
03/05/2019  V1.06 NWS Rain statements. Gust, Accumilated Rain total. Also added keyboard inputs to test 
                  filtered wind to make the needle less jumpy. Works OK CW but jumps CCW direction still.
03/06/2019  V1.06 Fixed logic bug in the fWind() function. Added min / max temp.  
03/17/2019  V1.07 Clean up - removed indoor functions. Now at 25028 bytes (78%) of program storage space.                  
                  Reset max/min temp at midnight.
04/23/2019  V1.08 Changed TFT Pins to match OSH Board.  Also the TFT
                  rotation from 3 > 5.  Back to station 2  as well/  
12/23/2019  V1.09 Added a scan feature that locks on any ISS.  Backed this out as it messes up RAIN 
                  Fixed Temp "MIN MAX" not to round up -- this was causing incorrect temps
                  TODO Min Max seem to be resetting at noon? - DONE Not a prolem - probabily caused by above change
01/08/2020  V1.10 Mass clean up.
                  Removing all unused features and libraties (INDOORS, Barometer etc.)  Motduino does not have 
                  enough capacity to add desired/needed features such as switch and logging

01/10/2020  V1.11 TODO LCD Backlight control.  DONE. Changed output to a PWM pin D5 was RTC INT.  
                  Mapped voltage from 16 - 255 seems to work fine.  No real change in RSSI 
                  values no PWM interference noted with backlight dimming. Works.    
                  TODO: Battery error DONE.
                  Added Day OF Week. Needed to use Adafruit/Jeelabs library, code was OK.  
                             
01/23/2020 V1.12  Added Button.h library!   Now able to set date and time w/o a PC.  All
                  settings seem to work OK.  I set the clock settings to be non-blocking of the reciever
                  operation so there is an issue with resposiveness but since this is a set up thing it
                  is not a daily user function i think it will be OK.  The whole settings thing works with
                  a global state machine.  the "GO!" ( enter ) key selects the cell to change. +/- incrs or
                  decs the numbers between ranges for HOURS, MINS, MONTH, DAY and YEAR.  SECONDs are reset with
                  HH and MM settings.  Updated a few print(F("....") 
                
02/10/2020 V1.12x Clean up the todo list...                   
                  (a) TODO - add button library  - Done!
                  (b) TODO - add set clock   - Done! 
                  (c) TODO -  Enter time/date  - Done! 
                  (d) TODO - Add ISS Chanel runtime select.  - DONE!
                  (e) TODO -  Max Wind gust of the day. DONE!
                  (f) TODO - Fix Temp and ISS Frames.  Missing line segments  DONE! 
                  (g) TODO - Daily MIN / MAX % REL HUMIDITY Displayed DONE!
                  (h) TODO - EEPROM To store ISS channel...Done (2/10/2020)
                  TODO - 
                  NOTE: Sketch uses 31220 bytes (98%) of program storage space. Maximum is 31744 bytes.
                          Global variables use 931 bytes of dynamic memory. W/O DEBUG ENABLED
                          
                  ISSUE:  Found on 2 instances the display was not locked up but radio was not updating
                  for several hours (4 AM - 8 AM) and 4PM Recovered @ 7PM by cycleing key modes. no RESET.
                  latest run seemss OK but may want to see if any changes ins V1.12 are responsible. May
                  also looke at backlight duty cycle.  Was able to wake the radio up by  cycling thru the
                  key modes, not sure if that was needed.  Keep an eye on this, may need to diff V10 and V11
                  UPDATE: May have been a loose conection?  Not seen since  

07/26/2020 V1.13x New Hardware Use with VP2TFT.kicad.pcb DWG 200118 REV D or later.
                  (a) TODO - New pin assignmnets  - Done!
                  (b) TFT Rotated 180 from proto - DONE!
                  (c) Reduce Backlight on battery power 
                  (d) Improved wind indicator smoothing (north crossing and fast large jumps) 

(not so) BIG TODO LIST REMAINING...
xx/xx/2019  V1.0x 
                 TODO: Remove all unused code, final release cleanup.
                 
                 TODO - EEPROM To store total rain, how many resets.
                  TODO: Dew Pt. Calculation? 
                  TODO:  WIND CHILL calculation? 

                  TODO:  SD Card / Logging  Too big for current Sketch!                       
NOTE: For <SD.h> Sketch uses 31912 bytes (100%) of program storage space. Maximum is 31744 bytes.
Global variables use 1708 bytes of dynamic memory.
Sketch too big; see http://www.arduino.cc/en/Guide/Troubleshooting#size for tips on reducing it.
Error compiling for board Moteino.

 

/*
 * //////////////////////////CHANGE MODES  V1.12/////////////////////////////////////
 * 
 * MODE
 * 0 = Running ACTION:  Normal mode, All screens updating, GO! key moves to next modes
 *     Only +/- will change.  GO! moves to next item. Items tat can be chnged are highlighted
 *     Data is sent  to RTC after each -/+ press. 
 * 1 = SET Hour.  calls SET_RTC_TIME Stops RTC UPDATE replaces screen with set screen
 *                (ENT) If enter w/out + or - keep currrent time and goto MODE2
 *                (+) INCREMENTS HH (00 -> 23) loops
 *                (-) DECREMENTS HH (23 -) 00) loops
 *                Sets Seconds to :00
 *                
 * 2 = Set Min     ENT) keeps current value and goto set minutes
 *                (+) INCREMENTS MM (00 -> 59)
 *                (-) DECREMENTS MM (59 -> 00)
 *                sets seconds to :00
 *                (ENT) go to next mode
 * 3 = SETMONTH   1 - 12  +, -, GO!
 * 4 = SET DAY    1 - 31  +, -, GO!       
 * 5 = SET YEAR   2020 - 2099 +, -, GO!  
 * 6 = SET ISS Channel  Sets channels 1 -> 8 ISS 0 = scan all channels! 
 * //////////////////////////CHANGE MODES/////////////////////////////////////
 * 
 * 
 * ////////////////////////DISPLAY Frames /////////////////////////////////////////
 * Here are where the various displays are located.  The positions use 
 * basic x, y and size in this format:
 *  drawRect(int16_t x, int16_t y, int16_t w, int16_t h, uint16_t color);
 *  from https://github.com/adafruit/Adafruit-GFX-Library/blob/master/Adafruit_GFX.h
 *  i didn't really plan the locations but they were added as needed. All the status 
 *  boxes on the right start at half way on the TFT and are 40 px high so the box 
 *  below is +40 from above. 
 *  
 * tft.drawRect(0, 0, tft.width(),40, ILI9341_BLUE); ///info+Clock Bar on top
 * tft.drawRect(0, 40, tft.width()/2,200, ILI9341_BLUE);  //Outlines the Wind Area
 * tft.drawRect(tft.width()/2, 40, tft.width()/2,40, ILI9341_BLUE);  //Temp Area norm   
 * tft.drawRect(tft.width()/2, 80, tft.width()/2,40, ILI9341_BLUE);  //Rh Area 
 * tft.drawRect(tft.width()/2, 120, tft.width()/2,40, ILI9341_BLUE);  //RAIN - old BAR Area
 * tft.drawRect(tft.width()/2+120, tft.height()/2+40, tft.width()/2,40, ILI9341_BLUE);  //ISS INFO
 * >>>>>>>>>>>>(tft.width()/2, 160, tft.width()/2,40, ILI9341_BLUE); //ISS Info
 * tft.drawRect(tft.width()/2, 200, tft.width()/2,40, ILI9341_BLUE);  //RADIO Area
 * 
 * 
 *****************************************************************************/

#define VERSION " v1.13d"        // Version of this program
#define TITLE "XyGyWx"
//#define TITLE "VP2_TFT"        //For display


/////////////////////Save Info Between Resets////////////////////////////////
//#include <SPIFlash.h>  //Use this for the Moteino External Flas part.
#include <EEPROM.h>  //else use the Arduino's EEPROM  V1.13(h)
////////////////////////////////////////////////////////////////////////////

#include "SPI.h"                //From standard Arduino library
#include <Adafruit_ILI9341.h>  //http://www.adafruit.com/products/1651
#include <DavisRFM69.h>       // From https://github.com/dekay/DavisRFM69 

//TODO: Include SD Card support for logging.

// For Mote (R6)Use hardware SPI like on Uno, #13, #12, #11) and the below for CS/DC
#define TFT_DC  6             // was 9
#define TFT_CS 7              //was 10

//Clock
#include <RTClib.h>           //Using Adafruit: https://github.com/adafruit/RTClib
///here are some scaled down versions for RTC ... may save some space...
//#include <RTC_DS3231.h>       // Need to try: https://github.com/mizraith/RTClib 
//#include <DS232RTC>           // Need to try: https://github.com/JChristensen/DS3232RTC
#include <Wire.h>             // From standard Arduino library
                             
//#define RTC_SQW_IN 5          // input square wave from RTC into T1 pin (D5)
                              // TIMER1 does not interfere with Arduino delay()
#define VP2 false       //we got us a Vantage VU ISS 
#define INDOORS false  //only report data from ISS on M6 (saving some room - needs Mega)

#if INDOORS //Display only outdoor sensors if FALSE ...most of these have been removed

//////DHT and BMP0805  was used for initial testing.  We are only getting data from ISS now.
#include <DHTxx.h>                             
#include "DHTxx.h"            //From: https://github.com/dekay/DavisRFM69
#define DHT_DATA_PIN    4     // Use pin D4 to talk to the DHT22
#include <Adafruit_BMP085.h>  //From: https://github.com/adafruit/Adafruit-BMP085-Library

#endif

//Other used pins:
#define LED               9       // Moteinos have LEDs on D9
#define GREEN_LED         9       // V13 OK was 1
#define RED_LED           A3       // V13 ERR was 0
#define LCD_PWM           3       // V13 LCD Backlight was 5

///Enable the buttons for settings
#include <Button.h>  //V1.12

Button PLUS_key(A0);  // PB1 V13 Was A1
Button MINUS_key(A2); // PB2
Button OK(A1);        // PB3 V13 Was A0
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
void loop(void) 
{
    int          w = tft.width(),
                 h = tft.height();
     bool UpdateScreen = true;            
    tft.setRotation(3);  //Landscape will be needed
    
// This was a TEST that  does all degress fast ...Not needed 
//  for(int ddd=0; ddd<360; ddd++) {

//TODO: get rid of this polling loop?
//if (radio.receiveDone()) {... // https://github.com/dekay/DavisRFM69/blob/master/Examples/VP2/VP2.ino
//bool haveFreshWeatherData = getWirelessData();
   
{
  static uint32_t lastRxTime = 0;  // timestamp of last received data.  Doesn't have to be good data
  static byte hopCount = 0;
  
  DispISS_Batt_Status(); //I put this in the main loop so i can flash the ERR if ISS Battery is bad 
   if (OK.pressed())  // only cycle to the next
         {
          //Serial.println("OK!");  
          Current_Op = None;  //Do no harm
          if (Current_Mode == RUNNING) Current_Mode = SET_HR; 
          else if (Current_Mode == SET_HR)  Current_Mode = SET_MIN;  
               else if (Current_Mode == SET_MIN)  Current_Mode =  SET_MONTH; 
                     else if (Current_Mode == SET_MONTH)  Current_Mode = SET_DAY;     
                            else if (Current_Mode == SET_DAY)  Current_Mode =  SET_YEAR;  
                                else if (Current_Mode == SET_YEAR)  Current_Mode = SET_ISS; 
                                       else if (Current_Mode == SET_ISS)  Current_Mode = RUNNING; 
          Display_Mode(); 
             // DisplayISS();                           
         }
    if(  PLUS_key.pressed()){
      //Serial.println("+"); 
       Current_Op = Inc; //None, Inc, Dec
       DisplaySetTime();  //do it!
       Current_Op = None;  //done and none!
    }
    if(  MINUS_key.pressed())  {
     // Serial.println("-");  
       Current_Op = Dec; //None, Inc, Dec
       DisplaySetTime();  //do it!
       Current_Op = None;  //done and none!
    }
    
     DisplaySetTime();
 // bool gotGoodData = false;  // Initialize
 //process any serial input]
#define DEBUG2  0
#if DEBUG2   
  if (Serial.available() > 0)
  {
    char input = Serial.read();
     if (input == 'i')
    {
      Serial.print("Listening to ISS: ");
//      Serial.println(((radio.DATA[0] & 0x07) + 1), HEX);  
      Serial.println(TRANSMITTER_STATION_ID, HEX);
    }  

         if (input == 'r')
    {
      Serial.print("increment Rain : ");
      ISS_dayRain++; // += 
      ISS_TotRain++;
      Serial.println(ISS_dayRain/100);         
     DisplayRainCell();  
    } 

           if (input == 'Z')
    {
      Serial.print("ZERO Day Rain : ");
       NewDay = true;  //was
      Serial.println(ISS_dayRain);         
//     DisplayRainCell();  //immeadiately do it 
    } 
/*
         if (input== '!')  // only cycle to the next
         {
          if (Current_Mode == RUNNING) Current_Mode = SET_HR; 
          else if (Current_Mode == SET_HR)  Current_Mode = SET_MIN;  
               else if (Current_Mode == SET_MIN)  Current_Mode =  SET_MONTH; 
                     else if (Current_Mode == SET_MONTH)  Current_Mode = SET_DAY;     
                            else if (Current_Mode == SET_DAY)  Current_Mode =  SET_YEAR;  
                                else if (Current_Mode == SET_YEAR)  Current_Mode = RUNNING;                             
// DEBUG

//          Serial.print("Incrementing Mode : "); 
//          Serial.println(Current_Mode);  

 
          Display_Mode();
         

         }
*/ 

       /*
        if (input == '<'){
          if (Current_Mode != RUNNING) {
              if (Current_Mode = SET_HR); {
               Serial.print("Dec HRs : ");                   
              }
              if (Current_Mode = SET_MIN); {
               Serial.print("Decr MINs : ");                   
              } 
              if (Current_Mode = SET_MONTH); {
               Serial.print("Dec Months : ");                   
              }  
              if (Current_Mode = SET_DAY); {
               Serial.print("Dec Days : ");                   
              }  
              if (Current_Mode = SET_YEAR); {
               Serial.print("Dec Years : "); 
              }  
            } //END if Running
  
          } //End Decrement
 */
          Display_Mode();     


/*    
 *     The following commands were for testing
 *     They are not needed once it got working
 *     I am keeping these that i can un comment if i need
 *     to test...
 *     
//RADIO REGISTERS
    if (input == 'r') //d=dump all register values
    {
      radio.readAllRegs();
      Serial.println();
    }
    
// FLASH TESTS   
    if (input == 'd') //d=dump flash area
    {
      Serial.println("Flash content:");
      int counter = 0;

      while(counter<=256){
        Serial.print(flash.readByte(counter++), HEX);
        Serial.print('.');
      }
      while(flash.busy());
      Serial.println();
    }
    if (input == 'e')
    {
      Serial.print("Erasing Flash chip ... ");
      flash.chipErase();
      while(flash.busy());
      Serial.println("DONE");
    }
    if (input == 'i')
    {
      Serial.print("DeviceID: ");
      word jedecid = flash.readDeviceId();
      Serial.println(jedecid, HEX);
    }
 */ 
//Read the radio temp... 
    if (input == 't')
    {
      byte temperature =  radio.readTemperature(-1); // -1 = user cal factor, adjust for correct ambient
      byte fTemp = 1.8 * temperature + 32; // 9/5=1.8
      Serial.print( "Radio Temp is ");
      Serial.print(temperature);
      Serial.print("C, ");
      Serial.print(fTemp); //converting to F loses some resolution, obvious when C is on edge between 2 values (ie 26C=78F, 27C=80F)
      Serial.println('F');
    }


//          Serial.print("Incrementing Mode : "); 
//          Serial.println(Current_Mode);  

 
          Display_Mode();
    DisplaySetTime();
  }
#endif

 //////////////////////////////////////////////
 // Process wireless ISS packet
 //////////////////////////////////////////////
  if ( radio.receiveDone() )
  {
    packetStats.packetsReceived++;
    // check CRC
    unsigned int crc = radio.crc16_ccitt(radio.DATA, 6);
    if ((crc == (word(radio.DATA[6], radio.DATA[7]))) && (crc != 0))
    {
      decodePacket();  
     if ( packetStats.receivedStreak < 100) packetStats.receivedStreak++;
     //Good stuff happened...
      hopCount = 1;
      blink(GREEN_LED, 50);
      blink(LED, 50); //??
      DisplayPacket();
      DisplayRadioData(true);
    }
    else  //Bad stuff happened
    {
      packetStats.crcErrors++;
//      packetStats.receivedStreak--;
   if ( packetStats.receivedStreak <= 0) packetStats.receivedStreak = 0;
     blink(RED_LED, 50);  
     packetStats.receivedStreak = 0;
     DisplayRadioData(false);  //this displays with RED 
    }
    
    // Whether CRC is right or not, we count that as reception and hop
    lastRxTime = micros()/1000UL;
    radio.hop();
  } // end if(radio.receiveDone())
  
  // If a packet was not received at the expected time, hop the radio anyway
  // in an attempt to keep up.  Give up after 25 failed attempts.  Keep track
  // of packet stats as we go.  I consider a consecutive string of missed
  // packets to be a single resync.  Thx to Kobuki for this algorithm.
  // Formula for packet interval = (40 + STATION ID)/16 seconds.  ID is Davis ISS ID, default is 1 (which is 0 in packet data)
  // See: http://www.wxforum.net/index.php?topic=24981.msg240797#msg240797 
  // Dekay uses 2555 for Packet Interval, see: http://git.io/vqDqS
  
  if(TRANSMITTER_STATION_ID ==0) { PACKET_INTERVAL = (40.0 + 1)/16.0 * 1000.0;  }  //Default = 2500
     else{ PACKET_INTERVAL = (40.0 + TRANSMITTER_STATION_ID)/16.0 * 1000.0;   }

  if ( (hopCount > 0) && (( (micros()/1000UL) - lastRxTime) > (hopCount * PACKET_INTERVAL + 200)) )
  {
    packetStats.packetsMissed++;
           blink(RED_LED, 5);
    if (hopCount == 1)
    { 
      packetStats.numResyncs++; 
       blink(RED_LED, 5);
    }
    
    if (++hopCount > 12)
    { hopCount = 0; }
    radio.hop();
  }

} // end getWirelessData()
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

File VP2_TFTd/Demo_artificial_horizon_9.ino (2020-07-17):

// Demo code for artifical horizon display
// Written by Bodmer for a 160 x 128 TFT display
// 16/8/16

#include <SPI.h>

// Use ONE of these three highly optimised libraries, comment out other two!

// For S6D02A1 based TFT displays
#include <TFT_S6D02A1.h>         // Bodmer's graphics and font library for S6D02A1 driver chip
TFT_S6D02A1 tft = TFT_S6D02A1(); // Invoke library, pins defined in User_Setup.h
//                                    https://github.com/Bodmer/TFT_S6D02A1

// For ST7735 based TFT displays
//#include <TFT_ST7735.h>          // Bodmer's graphics and font library for ST7735 driver chip
//TFT_ST7735 tft = TFT_ST7735();   // Invoke library, pins defined in User_Setup.h
//                                    https://github.com/Bodmer/TFT_ST7735

// For ILI9341 based TFT displays (note sketch is currently setup for a 160 x 128 display)
//#include <TFT_ILI9341.h>         // Bodmer's graphics and font library for ILI9341 driver chip
//TFT_ILI9341 tft = TFT_ILI9341(); // Invoke library, pins defined in User_Setup.h
//                                    https://github.com/Bodmer/TFT_ILI9341

#define REDRAW_DELAY 16 // minimum delay in milliseconds between display updates

#define HOR 172    // Horizon vector line length

#define BROWN      0x5140 //0x5960
#define SKY_BLUE   0x02B5 //0x0318 //0x039B //0x34BF
#define DARK_RED   0x8000
#define DARK_GREY  0x39C7

#define XC 64 // x coord of centre of horizon
#define YC 80 // y coord of centre of horizon

#define DEG2RAD 0.0174532925

int last_roll = 0; // the whole horizon graphic
int last_pitch = 0;


// Variables for test only
int test_roll = 0;
int delta = 0;

unsigned long redrawTime = 0;

// #########################################################################
// Setup, runs once on boot up
// #########################################################################

void setup(void) {
  Serial.begin(115200);

  tft.begin();
  tft.setRotation(0);

  tft.fillRect(0,  0, 128, 80, SKY_BLUE);
  tft.fillRect(0, 80, 128, 80, BROWN);

  // Draw the horizon graphic
  drawHorizon(0, 0);
  drawInfo();
  delay(2000); // Wait to permit visual check

  // Test roll and pitch
  testRoll();
  testPitch();

  tft.setTextColor(TFT_YELLOW, SKY_BLUE);
  tft.setTextDatum(TC_DATUM);            // Centre middle justified
  tft.drawString("Random", 64, 10, 1);
}


// #########################################################################
// Main loop, keeps looping around
// #########################################################################

void loop() {

  // Refresh the display at regular intervals
  if (millis() > redrawTime) {
    redrawTime = millis() + REDRAW_DELAY;

    // Roll is in degrees in range +/-180
    int roll = random(361) - 180;

    // Pitch is in y coord (pixel) steps, 20 steps = 10 degrees on drawn scale
    // Maximum pitch shouls be in range +/- 80 with HOR = 172
    int pitch = random (161) - 80;

    updateHorizon(roll, pitch);
  }
}

// #########################################################################
// Update the horizon with a new roll (angle in range -180 to +180)
// #########################################################################

void updateHorizon(int roll, int pitch)
{
  bool draw = 1;
  int delta_pitch = 0;
  int pitch_error = 0;
  int delta_roll  = 0;
  while ((last_pitch != pitch) || (last_roll != roll))
  {
    delta_pitch = 0;
    delta_roll  = 0;

    if (last_pitch < pitch) {
      delta_pitch = 1;
      pitch_error = pitch - last_pitch;
    }

    if (last_pitch > pitch) {
      delta_pitch = -1;
      pitch_error = last_pitch - pitch;
    }

    if (last_roll < roll) delta_roll  = 1;
    if (last_roll > roll) delta_roll  = -1;

    if (delta_roll == 0) {
      if (pitch_error > 1) delta_pitch *= 2;
    }

    drawHorizon(last_roll + delta_roll, last_pitch + delta_pitch);
    drawInfo();
  }
}

// #########################################################################
// Draw the horizon with a new roll (angle in range -180 to +180)
// #########################################################################

void drawHorizon(int roll, int pitch)
{
  // Calculate coordinates for line start
  float sx = cos(roll * DEG2RAD);
  float sy = sin(roll * DEG2RAD);

  int16_t x0 = sx * HOR;
  int16_t y0 = sy * HOR;
  int16_t xd = 0;
  int16_t yd = 1;
  int16_t xdn  = 0;
  int16_t ydn = 0;

  if (roll > 45 && roll <  135) {
    xd = -1;
    yd =  0;
  }
  if (roll >=  135)             {
    xd =  0;
    yd = -1;
  }
  if (roll < -45 && roll > -135) {
    xd =  1;
    yd =  0;
  }
  if (roll <= -135)             {
    xd =  0;
    yd = -1;
  }

  if ((roll != last_roll) && ((abs(roll) > 35)  || (pitch != last_pitch)))
  {
    xdn = 4 * xd;
    ydn = 4 * yd;
    tft.drawLine(XC - x0 - xdn, YC - y0 - ydn - pitch, XC + x0 - xdn, YC + y0 - ydn - pitch, SKY_BLUE);
    tft.drawLine(XC - x0 + xdn, YC - y0 + ydn - pitch, XC + x0 + xdn, YC + y0 + ydn - pitch, BROWN);
    xdn = 3 * xd;
    ydn = 3 * yd;
    tft.drawLine(XC - x0 - xdn, YC - y0 - ydn - pitch, XC + x0 - xdn, YC + y0 - ydn - pitch, SKY_BLUE);
    tft.drawLine(XC - x0 + xdn, YC - y0 + ydn - pitch, XC + x0 + xdn, YC + y0 + ydn - pitch, BROWN);
  }
  xdn = 2 * xd;
  ydn = 2 * yd;
  tft.drawLine(XC - x0 - xdn, YC - y0 - ydn - pitch, XC + x0 - xdn, YC + y0 - ydn - pitch, SKY_BLUE);
  tft.drawLine(XC - x0 + xdn, YC - y0 + ydn - pitch, XC + x0 + xdn, YC + y0 + ydn - pitch, BROWN);

  tft.drawLine(XC - x0 - xd, YC - y0 - yd - pitch, XC + x0 - xd, YC + y0 - yd - pitch, SKY_BLUE);
  tft.drawLine(XC - x0 + xd, YC - y0 + yd - pitch, XC + x0 + xd, YC + y0 + yd - pitch, BROWN);

  tft.drawLine(XC - x0, YC - y0 - pitch,   XC + x0, YC + y0 - pitch,   TFT_WHITE);

  last_roll = roll;
  last_pitch = pitch;

}

// #########################################################################
// Draw the information
// #########################################################################
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

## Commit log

2020-06-11 added Davis Instruments and Low Power Labs URLs
2020-06-11 KiCad Schematics and PCB Files
    [VP2_TFT_1.kicad_pcb, VP2_TFT_1.sch]
2020-06-11 Added Schematic & 3D rendering
2020-06-11 added PCB 3D renderings
2020-06-11 Added link to Power connector
2020-06-11 Added Links to LowPower Lab and BOM
2020-06-12 Parts + BOM
2020-06-13 SD Card Circuit Descriptons
2020-06-14 Modify Display circuits section
2020-06-14 Sensors sections added
2020-06-14 Sensor section format
2020-06-15 LED table added
2020-06-15 Added LiPo Battery description
2020-06-15 Display Pictures uploaded
    [VP2_TFT_1.kicad_pcb, VP2_TFT_1.sch]
2020-06-16 Antenna Info
2020-06-16 Battery info updates
2020-06-16 Battery info updated
2020-06-16 Clean ups and added Connector Table
2020-06-16 Connectors, Jumpers, and Test points
2020-06-17 Format BOM to PDF File
2020-06-19 Changed BOM to .xlsx
    Easier to use than .pdf
    [VP2_TFT_1.xlsx]
2020-06-19 BOM Link to the .xlsx file
    https://github.com/b-wave/VP2_TFT-Weather-Receiver/blob/master/Hardware/VP2_TFT_1.xlsx
2020-06-19 Update Board description.
2020-06-20 Battery description
2020-08-08 New V1.13 - board supported
    New Hardware Use with VP2TFT.kicad.pcb DWG 200118 REV D or later.
    (a) TODO - New pin assignments - Done!
    (b) TFT Rotated 180 from proto - DONE!
    (c) Reduce Backlight on battery power
    (d) Improved wind direction indicator smoothing (north crossing and fast(er) large jumps)

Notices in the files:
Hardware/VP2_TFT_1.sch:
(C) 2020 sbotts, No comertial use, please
